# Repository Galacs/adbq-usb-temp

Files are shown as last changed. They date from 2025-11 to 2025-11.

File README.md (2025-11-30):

# ADBQ USB temperature sensor

ESP32-S3 based temperature USB-C compact sensor board made to test small step-down power supply design, i2c ambient temperature sensors, led segment displays and custom class USB peripherals.

## IC List

- ESP32-S3 (Main MCU)
- 2x TMP117 (I2C temperature sensor)
- TPS6282 (Low Iq buck converter)
- 2450AT18A100E (2.45GHz Ceramic chip antenna)
- XL-SB2301SRWC (SMD 3 digit segment display)

## Top preview



## Preview 3d render



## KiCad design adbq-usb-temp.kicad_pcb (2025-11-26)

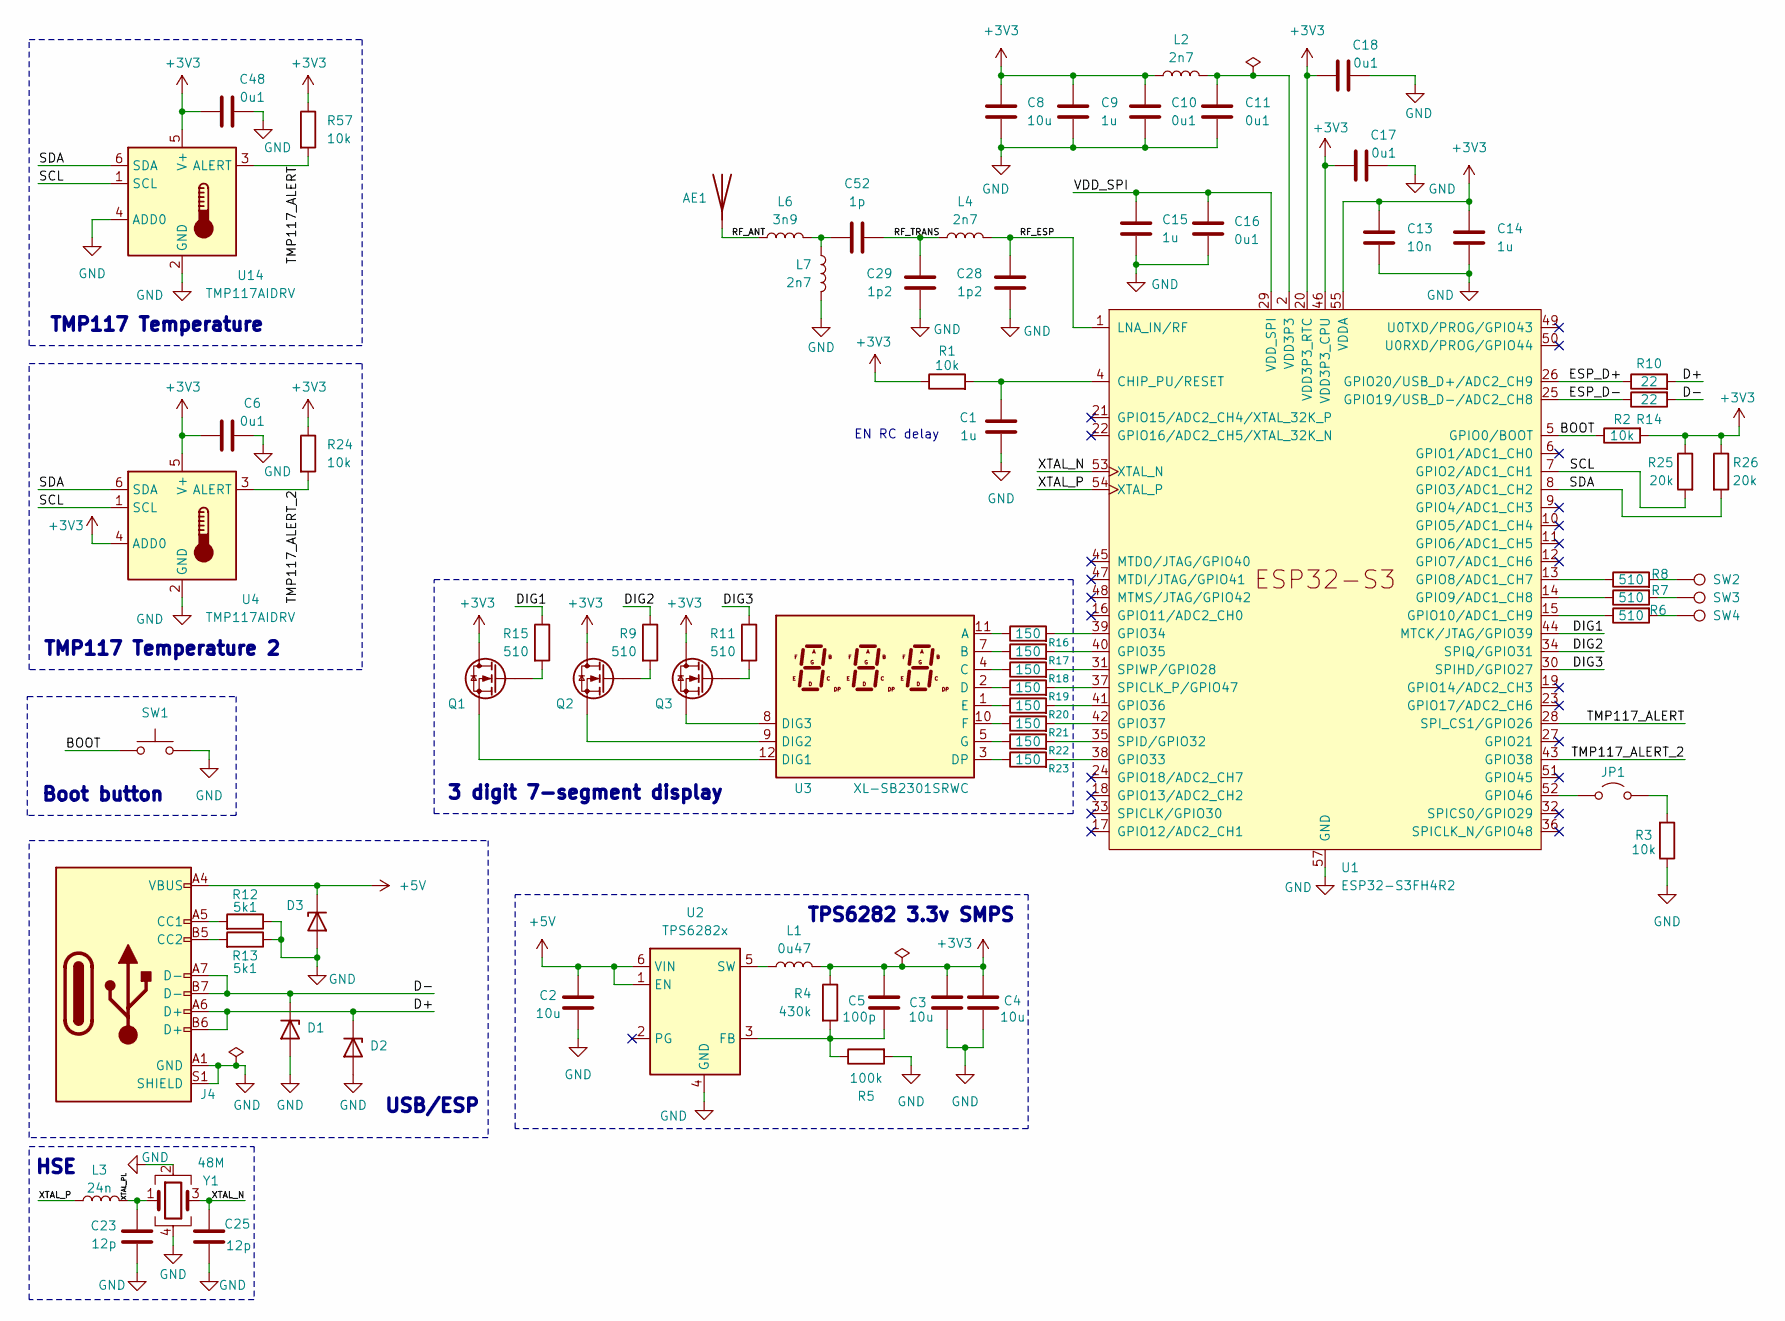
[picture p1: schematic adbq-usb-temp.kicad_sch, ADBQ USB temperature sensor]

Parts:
AE1: Antenna; Johanson_2450AT18x100; Manufacturer Part Number 2450AT18A100E; JLCPCB Part # C89334
C1, C9, C14, C15: 1u; C_0402_1005Metric; Manufacturer Part Number CL05A105KA5NQNC; JLCPCB Part # C52923
C2: 10u; C_0603_1608Metric; Manufacturer Part Number CL10A106KP8NNNC; JLCPCB Part # C19702
C3, C4, C8: 10u; C_0402_1005Metric; Manufacturer Part Number CL05A106MQ5NUNC; JLCPCB Part # C15525
C5: 100p; C_0402_1005Metric; Manufacturer Part Number 0402CG101J500NT; JLCPCB Part # C1546
C6, C10, C11, C16, C17, C18, C48: 0u1; C_0402_1005Metric; Manufacturer Part Number CL05B104KB54PNC; JLCPCB Part # C307331
C13: 10n; C_0402_1005Metric; Manufacturer Part Number CL05B103KB5NNNC; JLCPCB Part # C15195
C23, C25: 12p; C_0402_1005Metric; Manufacturer Part Number 0402CG120J500NT; JLCPCB Part # C1547
C28, C29: 1p2; C_0402_1005Metric; Manufacturer Part Number GJM1555C1H1R2WB01D; JLCPCB Part # C76899
C52: 1p; C_0402_1005Metric; Manufacturer Part Number 0402CG1R0C500NT; JLCPCB Part # C1550
D1, D2, D3: H5VU10U; Diode_DFN1006; Manufacturer Part Number H5VU10U; JLCPCB Part # C22395519
J4: USB_C_Receptacle_USB2.0_14P; USB_C_Receptacle_HRO_TYPE-C-31-M-12; Manufacturer Part Number TYPE-C16PIN; JLCPCB Part # C393939
JP1: Jumper_2_Open; SolderJumper-2_P1.3mm_Open_RoundedPad1.0x1.5mm
L1: 0u47; TDK_TFM201610ALC; Manufacturer Part Number TFM201610ALC-R47MTAA; JLCPCB Part # C2045043
L2, L4, L7: 2n7; L_0402_1005Metric; Manufacturer Part Number LQG15HS2N7S02D; JLCPCB Part # C77108
L3: 24n; L_0402_1005Metric; Manufacturer Part Number LQW15AN24NG00D; JLCPCB Part # C167472
L6: 3n9; L_0402_1005Metric; Manufacturer Part Number LQG15HS3N9S02D; JLCPCB Part # C77109
Q1, Q2, Q3: Q_NMOS; SOT-323_SC-70; Manufacturer Part Number BSS138W; JLCPCB Part # C28646265
R1, R2, R3, R24, R57: 10k; R_0402_1005Metric; Manufacturer Part Number 0402WGF1002TCE; JLCPCB Part # C25744
R4: 430k; R_0603_1608Metric; Manufacturer Part Number 0603WAF4303T5E; JLCPCB Part # C25969
R5: 100k; R_0402_1005Metric; Manufacturer Part Number 0402WGF1003TCE; JLCPCB Part # C25741
R6, R7, R8, R9, R11, R15: 510; R_0402_1005Metric; Manufacturer Part Number 0402WGF5100TCE; JLCPCB Part # C25123
R10, R14: 22; R_0402_1005Metric; Manufacturer Part Number 0402WGF220JTCE; JLCPCB Part # C25092
R12, R13: 5k1; R_0402_1005Metric; Manufacturer Part Number 0402WGF5101TCE; JLCPCB Part # C25905
R16, R17, R18, R19, R20, R21, R22, R23: 150; R_0402_1005Metric; Manufacturer Part Number 0402WGF1500TCE; JLCPCB Part # C25082
R25, R26: 20k; R_0402_1005Metric; Manufacturer Part Number 0402WGF2002TCE; JLCPCB Part # C25765
SW1: SW_Push; SolderJumper-2_P1.3mm_Open_RoundedPad1.0x1.5mm
SW2, SW3, SW4: TestPoint; TestPoint_Pad_D1.5mm
U1: ESP32-S3FH4R2; QFN-56-1EP_7x7mm_P0.4mm_EP5.6x5.6mm; Manufacturer Part Number ESP32-S3FH4R2; JLCPCB Part # C3013940
U2: TPS6282x; Texas_VSON-6_1.5x1.5mm_P0.5mm_DMQ0006A; Manufacturer Part Number TPS62825DMQR; JLCPCB Part # C2650334
U3: XL-SB2301SRWC
U4, U14: TMP117AIDRV; WSON-6-1EP_2x2mm_P0.65mm_EP1x1.6mm; Manufacturer Part Number TMP117AIDRVR; JLCPCB Part # C699536
Y1: 48M; Crystal_SMD_2016-4Pin_2.0x1.6mm; Manufacturer Part Number R940000096; JLCPCB Part # C7206306

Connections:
+3V3: C3.1, C4.1, C5.1, C6.1, C8.1, C9.1, C10.1, C13.1, C14.1, C17.1, C18.1, C48.1, L1.2, L2.1, Q1.3 (D), Q2.3 (D), Q3.3 (D), R1.1, R2.2, R4.1, R24.1, R25.1, R26.1, R57.1, U1.20 (VDD3P3_RTC), U1.46 (VDD3P3_CPU), U1.55 (VDDA), U1.56 (VDDA), U4.4 (ADD0), U4.5 (V+), U14.5 (V+)
+5V: C2.1, D3.1 (K), J4.A4 (VBUS), J4.A9 (VBUS), J4.B4 (VBUS), J4.B9 (VBUS), U2.1 (EN), U2.6 (VIN)
/BOOT: R2.1, SW1.1, U1.5 (GPIO0/BOOT)
/D+: D2.1 (K), J4.A6 (D+), J4.B6 (D+), R10.2
/D-: D1.1 (K), J4.A7 (D-), J4.B7 (D-), R14.2
/DIG1: R15.1, U1.44 (MTCK/JTAG/GPIO39)
/DIG2: R9.1, U1.34 (SPIQ/GPIO31)
/DIG3: R11.1, U1.30 (SPIHD/GPIO27)
/ESP_D+: R10.1, U1.26 (GPIO20/USB_D+/ADC2_CH9)
/ESP_D-: R14.1, U1.25 (GPIO19/USB_D-/ADC2_CH8)
/RF_ANT: AE1.1 (A), L6.1
/RF_ESP: C28.1, L4.2, U1.1 (LNA_IN/RF)
/RF_TRANS: C29.1, C52.1, L4.1
/SCL: R25.2, U1.7 (GPIO2/ADC1_CH1), U4.1 (SCL), U14.1 (SCL)
/SDA: R26.2, U1.8 (GPIO3/ADC1_CH2), U4.6 (SDA), U14.6 (SDA)
/TMP117_ALERT: R57.2, U1.28 (SPI_CS1/GPIO26), U14.3 (ALERT)
/TMP117_ALERT_2: R24.2, U1.43 (GPIO38), U4.3 (ALERT)
/VDD_SPI: C15.1, C16.1, U1.29 (VDD_SPI)
/XTAL_N: C25.1, U1.53 (XTAL_N), Y1.3
/XTAL_P: L3.1, U1.54 (XTAL_P)
/XTAL_PL: C23.2, L3.2, Y1.1
GND: C1.2, C2.2, C3.2, C4.2, C6.2, C8.2, C9.2, C10.2, C11.2, C13.2, C14.2, C15.2, C16.2, C17.2, C18.2, C23.1, C25.2, C28.2, C29.2, C48.2, D1.2 (A), D2.2 (A), D3.2 (A), J4.A1 (GND), J4.A12 (GND), J4.B1 (GND), J4.B12 (GND), J4.S1 (SHIELD), L7.1, R3.1, R5.2, R12.1, R13.1, SW1.2, U1.57 (GND), U2.4 (GND), U4.2 (GND), U14.2 (GND), U14.4 (ADD0), U14.7, Y1.2, Y1.4
unnamed: C52.2, L6.2, L7.2
unnamed: J4.A5 (CC1), R12.2
unnamed: J4.B5 (CC2), R13.2
unnamed: JP1.1 (A), U1.52 (GPIO46)
unnamed: JP1.2 (B), R3.2
unnamed: Q1.1 (G), R15.2
unnamed: Q1.2 (S), U3.12 (DIG1)
unnamed: Q2.1 (G), R9.2
unnamed: Q2.2 (S), U3.9 (DIG2)
unnamed: Q3.1 (G), R11.2
unnamed: Q3.2 (S), U3.8 (DIG3)
unnamed: R6.2, SW4.1
unnamed: R7.2, SW3.1
unnamed: R8.2, SW2.1
unnamed: C1.1, R1.2, U1.4 (CHIP_PU/RESET)
unnamed: R8.1, U1.13 (GPIO8/ADC1_CH7)
unnamed: R7.1, U1.14 (GPIO9/ADC1_CH8)
unnamed: R6.1, U1.15 (GPIO10/ADC1_CH9)
unnamed: R23.2, U1.38 (GPIO33)
unnamed: R16.2, U1.39 (GPIO34)
unnamed: R17.2, U1.40 (GPIO35)
unnamed: R20.2, U1.41 (GPIO36)
unnamed: R21.2, U1.42 (GPIO37)
unnamed: R19.2, U1.37 (SPICLK_P/GPIO47)
unnamed: R22.2, U1.35 (SPID/GPIO32)
unnamed: R18.2, U1.31 (SPIWP/GPIO28)
unnamed: C5.2, R4.2, R5.1, U2.3 (FB)
unnamed: L1.1, U2.5 (SW)
unnamed: R16.1, U3.11 (A)
unnamed: R17.1, U3.7 (B)
unnamed: R18.1, U3.4 (C)
unnamed: R19.1, U3.2 (D)
unnamed: R23.1, U3.3 (DP)
unnamed: R20.1, U3.1 (E)
unnamed: R21.1, U3.10 (F)
unnamed: R22.1, U3.5 (G)
TMP_PAD_2: U4.7
VDD3P3: C11.1, L2.2, U1.2 (VDD3P3), U1.3 (VDD3P3)

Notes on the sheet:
TMP117 Temperature
USB/ESP
TPS6282 3.3v SMPS
HSE
EN RC delay
TMP117 Temperature 2
Boot button
3 digit 7-segment display

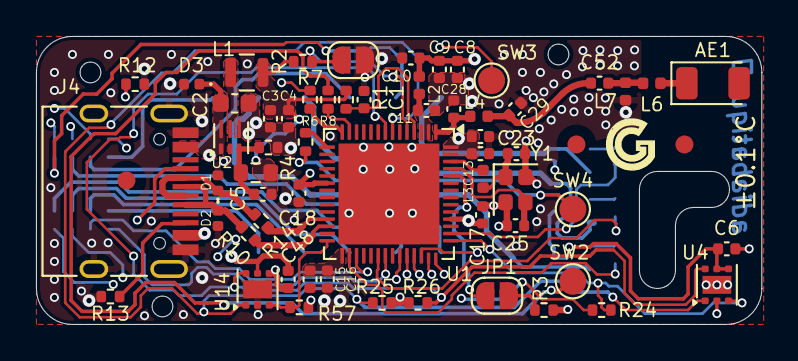
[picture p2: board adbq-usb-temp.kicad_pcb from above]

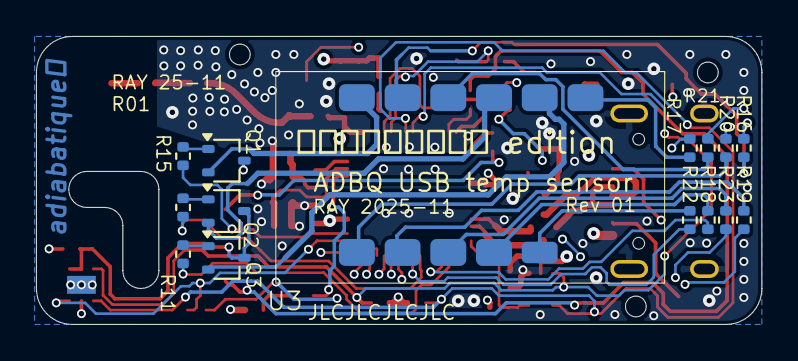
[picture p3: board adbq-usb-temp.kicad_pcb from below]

Board: 4 copper layers, 40.3 x 16.0 mm, 74 parts (15 on the bottom side), 59 nets.

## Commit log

2025-10-09 schem: add ESP32-S3FH4R2 symbol
    [adbq-usb-temp.kicad_sch]
2025-10-09 schem: add ESP32 decoupling caps
    [adbq-usb-temp.kicad_sch]
2025-10-09 schem: add rf antenna and matching networks
    [adbq-usb-temp.kicad_sch]
2025-10-09 schem: add HSE crystal
    [adbq-usb-temp.kicad_sch]
2025-10-09 schem: add usb c connector
    [adbq-usb-temp.kicad_sch]
2025-10-17 schem: add esp32 en pullup
    [adbq-usb-temp.kicad_sch]
2025-10-17 schem: add TMP117 temperature sensor
    [adbq-usb-temp.kicad_sch]
2025-10-23 POC(schem): remove USB-C diode
    [adbq-usb-temp.kicad_sch]
2025-10-23 POC(schem): replace usb TVS array with TVS diodes
    [adbq-usb-temp.kicad_sch]
2025-11-14 schem: remove usb 5v capacitor
    [adbq-usb-temp.kicad_sch]
2025-11-14 schem: add TPS6282 symbol and circuit
    [adbq-usb-temp.kicad_sch]
2025-11-14 schem: add TPS6282 components values
    [adbq-usb-temp.kicad_sch]
2025-11-14 schem: add touch inputs
    [adbq-usb-temp.kicad_sch]
2025-11-14 schem: add 3d digit segment display
    [adbq-usb-temp.kicad_sch]
2025-11-14 schem: add second TMP117 temperature sensor
    [adbq-usb-temp.kicad_sch]
2025-11-14 schem: add no connects
    [adbq-usb-temp.kicad_sch]
2025-11-14 schem: run and fix ERC
    [adbq-usb-temp.kicad_sch]
2025-11-14 schem: add i2c pullup
    [adbq-usb-temp.kicad_sch]
2025-11-14 schem: connect TMP117 altert pins to MCU
    [adbq-usb-temp.kicad_sch]
2025-11-14 schem: add title
    [adbq-usb-temp.kicad_sch]
2025-11-14 schem: assign footprints
    [adbq-usb-temp.kicad_sch]
2025-11-14 schem: add part numbers
    [adbq-usb-temp.kicad_sch]
2025-11-14 pcb: create file
    [adbq-usb-temp.kicad_pcb]
2025-11-14 pcb: import stackup
    [adbq-usb-temp.kicad_pcb]
2025-11-14 schem: update MOSFETs pin numbers
    [adbq-usb-temp.kicad_sch]
2025-11-14 pcb: import footprints from schematic
    [adbq-usb-temp.kicad_pcb]
2025-11-14 pcb: add missing 3d models
    [adbq-usb-temp.kicad_pcb, adbq-usb-temp.kicad_sch]
2025-11-14 pcb: inital rough placement
    [adbq-usb-temp.kicad_pcb]
2025-11-14 pcb: layout refinement
    [adbq-usb-temp.kicad_pcb]
2025-11-14 pcb: area reduction
    [adbq-usb-temp.kicad_pcb]
2025-11-14 pcb: add board outline
    [adbq-usb-temp.kicad_pcb, adbq-usb-temp.kicad_sch]
2025-11-14 pcb: add inner gnd planes
    [adbq-usb-temp.kicad_pcb]
2025-11-14 pcb: add tooling holes
    [adbq-usb-temp.kicad_pcb]
2025-11-14 pcb: add fiducials
    [adbq-usb-temp.kicad_pcb]
2025-11-14 pcb: add gnd vias
    [adbq-usb-temp.kicad_pcb]
2025-11-14 pcb: add rf routing
    [adbq-usb-temp.kicad_pcb]
2025-11-14 pcb: add HSE routing
    [adbq-usb-temp.kicad_pcb]
2025-11-14 pcb: add USB routing
    [adbq-usb-temp.kicad_pcb]
2025-11-14 pcb: add SMPS routing
    [adbq-usb-temp.kicad_pcb, adbq-usb-temp.kicad_sch]
2025-11-14 pcb: add GPIO46 strapping routing
    [adbq-usb-temp.kicad_pcb]
2025-11-14 pcb: add i2c routing
    [adbq-usb-temp.kicad_pcb, adbq-usb-temp.kicad_sch]
2025-11-14 pcb: add segment display routing
    [adbq-usb-temp.kicad_pcb, adbq-usb-temp.kicad_sch]
2025-11-14 pcb: add dril/place origin
    [adbq-usb-temp.kicad_pcb]
2025-11-15 pcb: add TMP117 routing
    [adbq-usb-temp.kicad_pcb, adbq-usb-temp.kicad_sch]
2025-11-15 pcb: finish USB routing
    [adbq-usb-temp.kicad_pcb]
2025-11-15 pcb: add 3v3 routing
    [adbq-usb-temp.kicad_pcb]
2025-11-15 pcb: add edge TMP117 pad and keepout
    [adbq-usb-temp.kicad_pcb]
2025-11-15 pcb: add TMP117 board cutout
    [adbq-usb-temp.kicad_pcb]
2025-11-15 pcb: add top GND pour
    [adbq-usb-temp.kicad_pcb]
2025-11-15 pcb: add stitching vias
    [adbq-usb-temp.kicad_pcb]
2025-11-15 pcb: clean tracks
    [adbq-usb-temp.kicad_pcb, adbq-usb-temp.kicad_sch]
2025-11-15 pcb: run and fix DRC
    [adbq-usb-temp.kicad_pcb]
2025-11-15 pcb: clean bottom and top silkscreen
    [adbq-usb-temp.kicad_pcb]
2025-11-15 pcb: add title
    [adbq-usb-temp.kicad_pcb]
2025-11-15 pcb: add bottom silkscreen
    [adbq-usb-temp.kicad_pcb]
2025-11-15 pcb: remove unused internal pads
    [adbq-usb-temp.kicad_pcb]
2025-11-16 pcb: add production files
    [adbq-usb-temp.kicad_pcb, adbq-usb-temp.kicad_sch]
2025-11-26 schem: update segment display mosfets to correct led polarities
    [adbq-usb-temp.kicad_sch]
2025-11-26 pcb: fix segment display layout and run ERC
    [adbq-usb-temp.kicad_pcb, adbq-usb-temp.kicad_sch]
